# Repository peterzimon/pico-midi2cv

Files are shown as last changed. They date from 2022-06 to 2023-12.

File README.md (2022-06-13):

# MIDI to CV converter



## About
A simple MIDI to CV converter using MCP4288 DAC.

## Dependecies
Uses [`pico-lib`](https://github.com/peterzimon/pico-lib) submodule. Clone and pull 
with `--recurse-submodules`, or use `git submodule update --init` once cloned. 

Alternatively you can set `git config submodule.recurse true` or `git config --global submodule.recurse true`.

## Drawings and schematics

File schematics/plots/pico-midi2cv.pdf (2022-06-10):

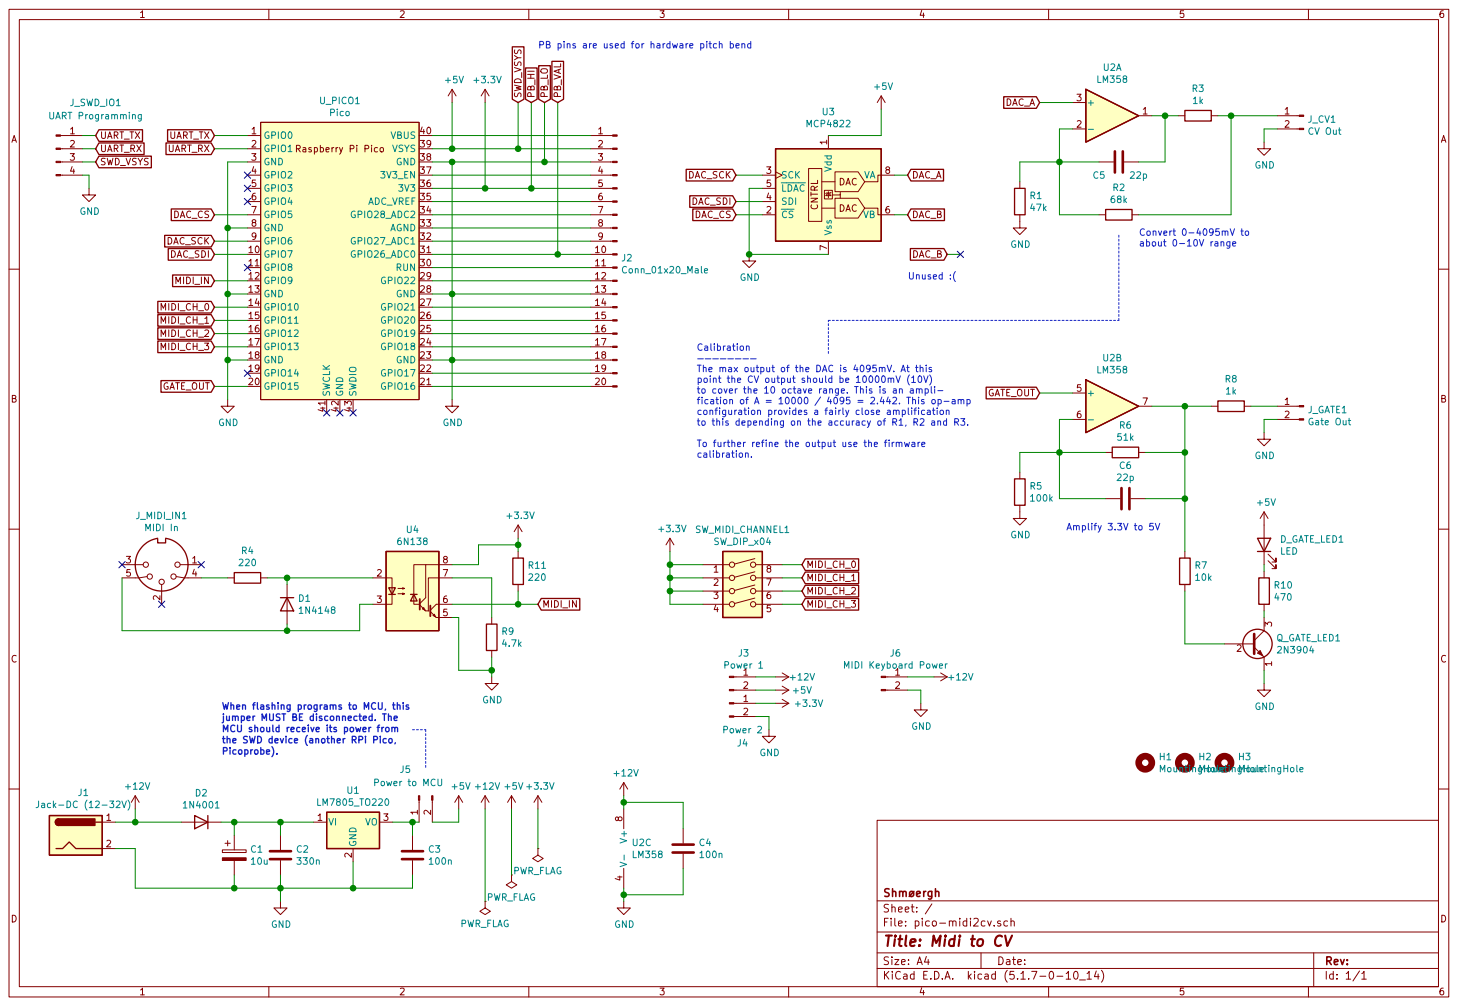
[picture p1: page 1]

Amplify 3.3V to 5V Calibration The max output of the DAC is 4095mV. At this

point the CV output should be 10000mV (10V)
to cover the 10 octave range. This is an ampli-
fication of A = 10000 / 4095 = 2.442. This op-amp
configuration provides a fairly close amplification
to this depending on the accuracy of R1, R2 and R3.

To further refine the output use the firmware

When flashing programs to MCU, this
jumper MUST BE disconnected. The
MCU should receive its power from
the SWD device (another RPi Pico,
Picoprobe).

File: pico-midi2cv.sch Sheet: / Shmøergh

Id: 1/1 Title: Midi to CV

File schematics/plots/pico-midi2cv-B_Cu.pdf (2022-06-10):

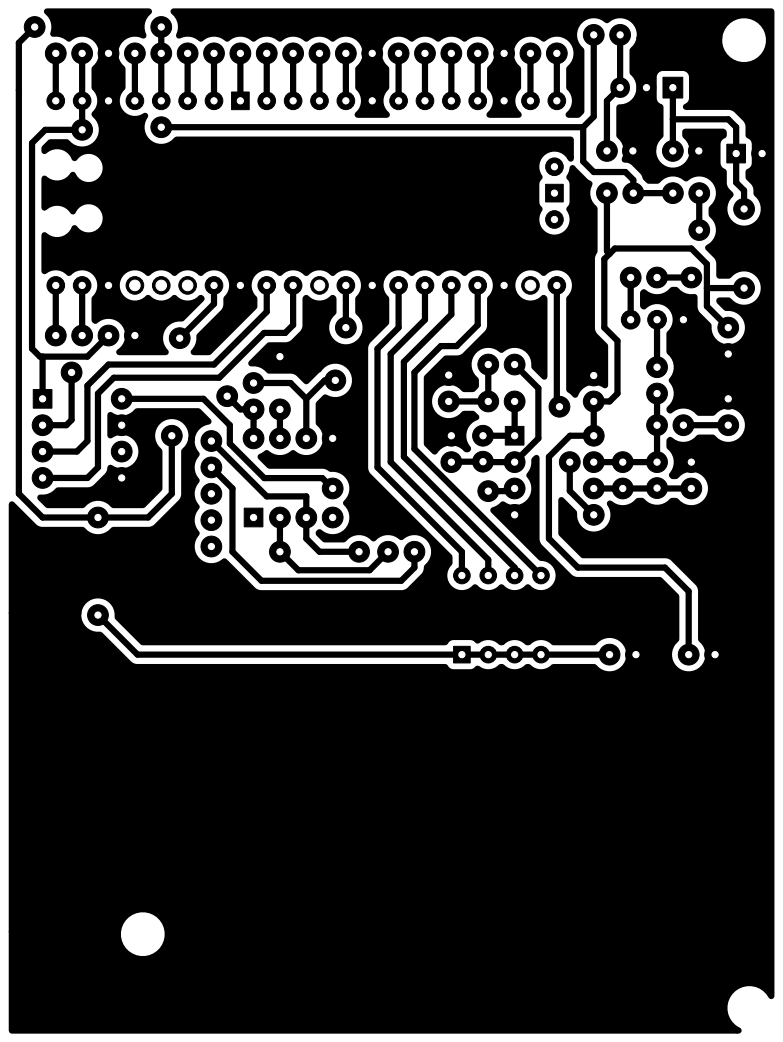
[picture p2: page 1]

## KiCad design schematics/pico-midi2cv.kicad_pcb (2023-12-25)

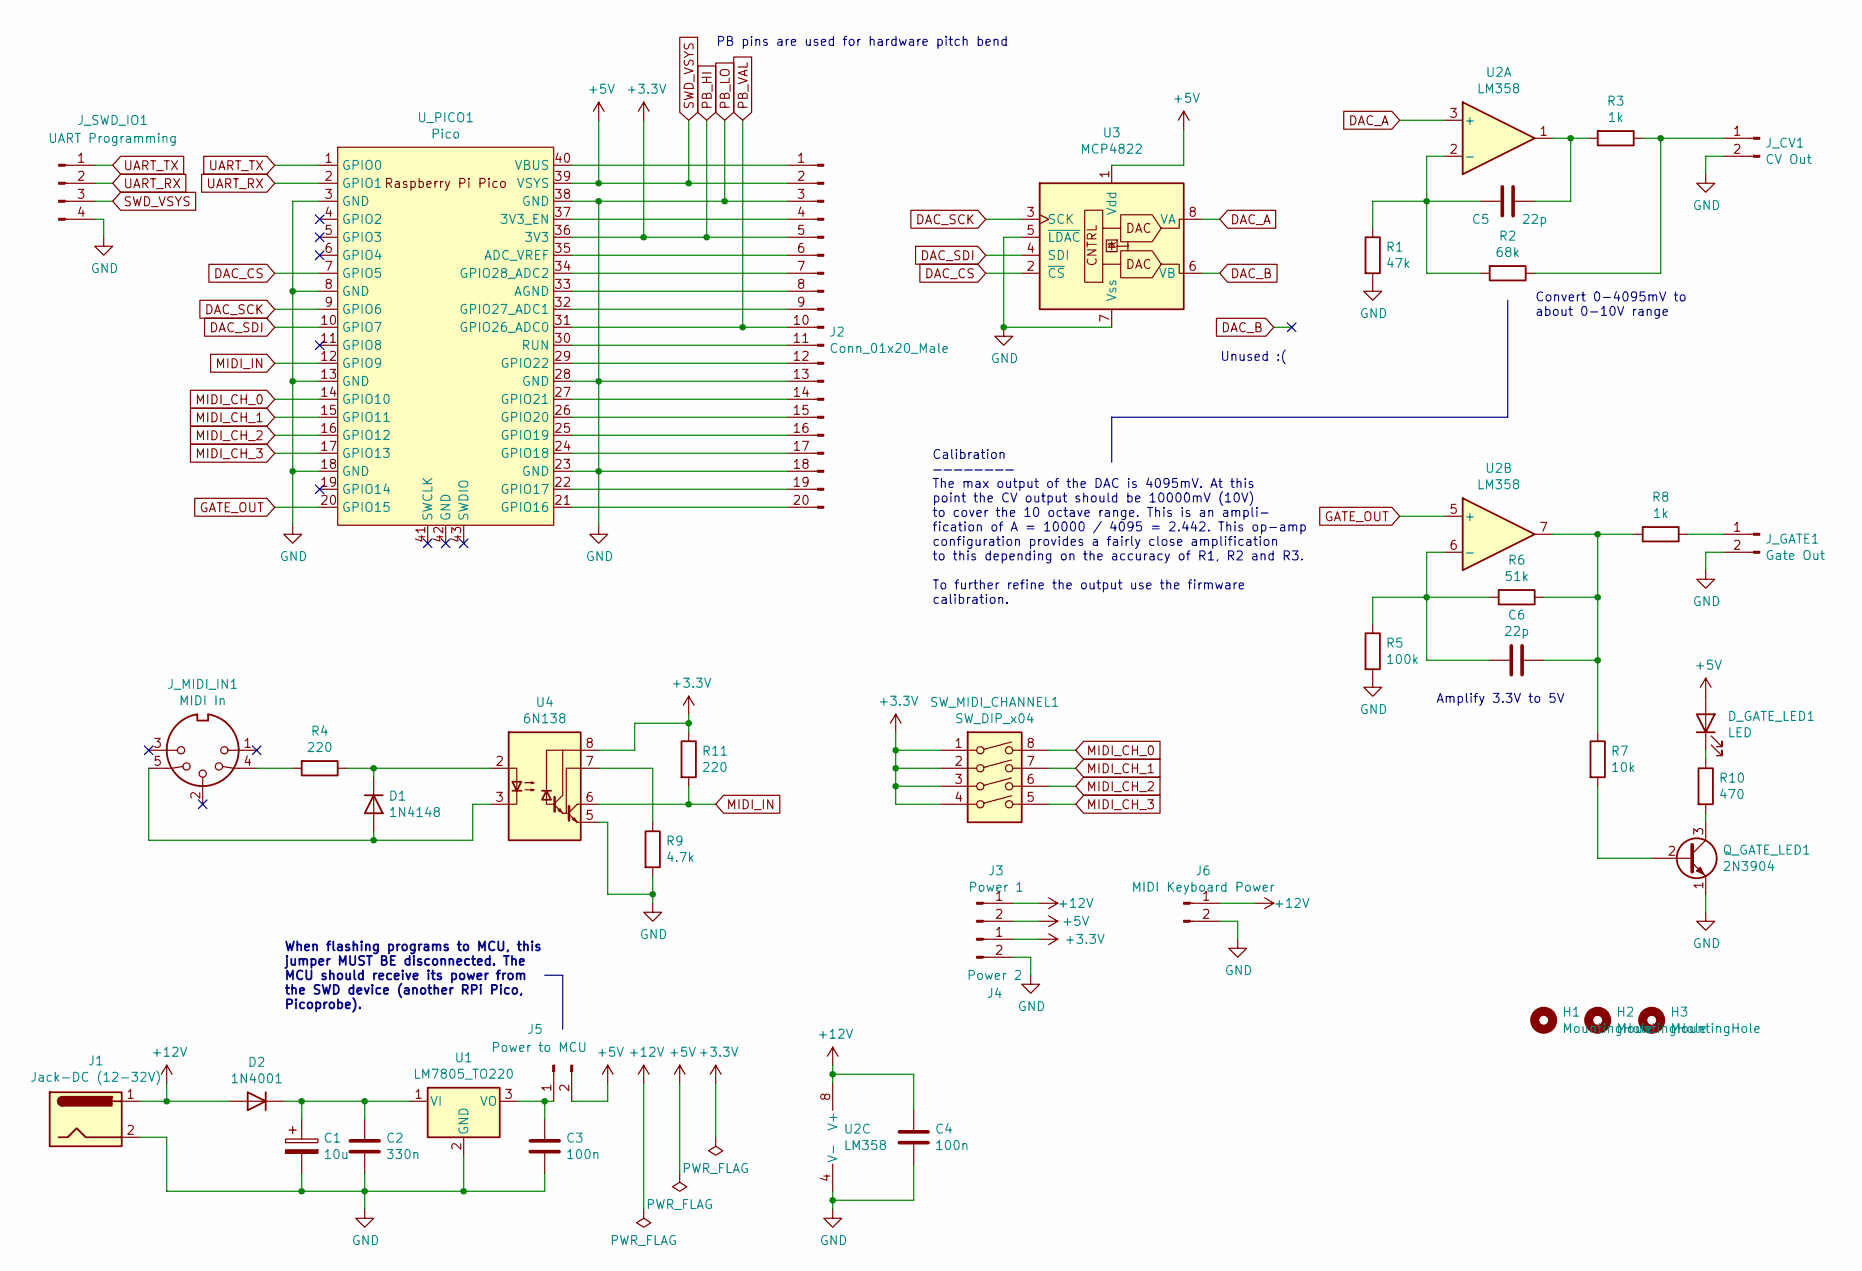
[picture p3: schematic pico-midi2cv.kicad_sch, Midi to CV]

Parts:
C1: 10u; CP_Radial_D5.0mm_P2.50mm
C2: 330n; C_Disc_D5.0mm_W2.5mm_P2.50mm
C3, C4: 100n; C_Disc_D5.0mm_W2.5mm_P2.50mm
C5, C6: 22p; C_Disc_D5.0mm_W2.5mm_P2.50mm
D1: 1N4148; D_Axial
D2: 1N4001; D_Axial
D_GATE_LED1: LED; NSL25_01x02_Vertical
H1, H2, H3: MountingHole; MountingHole_3mm
J1: Jack-DC (12-32V); NSL25_01x02_Vertical
J2: Conn_01x20_Male; PinOut_01x20
J3: Power 1; NSL25_01x02_Vertical
J4: Power 2; NSL25_01x02_Vertical
J5: Power to MCU; PinOut_01x02
J6: MIDI Keyboard Power; NSL25_01x02_Vertical
J_CV1: CV Out; NSL25_01x02_Vertical
J_GATE1: Gate Out; NSL25_01x02_Vertical
J_MIDI_IN1: MIDI In; PinOut_01x05
J_SWD_IO1: UART Programming; PinOut_01x04
Q_GATE_LED1: 2N3904; TO-92_Inline_Wide
R1: 47k; R_Axial_Vertical
R2: 68k; R_Axial_Vertical
R3, R8: 1k; R_Axial_Vertical
R4, R11: 220; R_Axial_Vertical
R5: 100k; R_Axial_Vertical
R6: 51k; R_Axial_Vertical
R7: 10k; R_Axial_Vertical
R9: 4.7k; R_Axial_Vertical
R10: 470; R_Axial_Vertical
SW_MIDI_CHANNEL1: SW_DIP_x04; SW_DIP_SPSTx04_Slide_6.7x11.72mm_W7.62mm_P2.54mm_LowProfile
U1: LM7805_TO220; TO-220-3_Vertical
U2: LM358; DIP-8_W7.62mm
U3: MCP4822; DIP-8_W7.62mm
U4: 6N138; DIP-8_W7.62mm
U_PICO1: Pico; RPi_Pico_SMD_TH

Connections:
+12V: C4.1, D2.2 (A), J1.1, J3.1, J6.1, U2.8 (V+)
DAC_A: U2.3 (+), U3.8 (VA)
DAC_B: U3.6 (VB)
DAC_CS: U3.2 (~CS), U_PICO1.7 (GPIO5)
DAC_SCK: U3.3 (SCK), U_PICO1.9 (GPIO6)
DAC_SDI: U3.4 (SDI), U_PICO1.10 (GPIO7)
GATE_OUT: U2.5 (+), U_PICO1.20 (GPIO15)
MIDI_CH_0: SW_MIDI_CHANNEL1.8, U_PICO1.14 (GPIO10)
MIDI_CH_1: SW_MIDI_CHANNEL1.7, U_PICO1.15 (GPIO11)
MIDI_CH_2: SW_MIDI_CHANNEL1.6, U_PICO1.16 (GPIO12)
MIDI_CH_3: SW_MIDI_CHANNEL1.5, U_PICO1.17 (GPIO13)
MIDI_IN: R11.2, U4.6 (VO2), U_PICO1.12 (GPIO9)
unnamed: C1.1, C2.1, D2.1 (K), U1.1 (VI)
unnamed: C3.1, J5.1, U1.3 (VO)
unnamed: C5.1, R3.2, U2.1
unnamed: C5.2, R1.1, R2.2, U2.2 (-)
unnamed: C6.1, R6.1, R7.1, R8.2, U2.7
unnamed: C6.2, R5.1, R6.2, U2.6 (-)
unnamed: D1.1 (K), R4.1, U4.2 (C1)
unnamed: D1.2 (A), J_MIDI_IN1.5, U4.3 (C2)
unnamed: D_GATE_LED1.1 (K), R10.1
unnamed: J2.1, U_PICO1.40 (VBUS)
unnamed: J2.4, U_PICO1.37 (3V3_EN)
unnamed: J2.6, U_PICO1.35 (ADC_VREF)
unnamed: J2.7, U_PICO1.34 (GPIO28_ADC2)
unnamed: J2.8, U_PICO1.33 (AGND)
unnamed: J2.9, U_PICO1.32 (GPIO27_ADC1)
unnamed: J2.11, U_PICO1.30 (RUN)
unnamed: J2.12, U_PICO1.29 (GPIO22)
unnamed: J2.14, U_PICO1.27 (GPIO21)
unnamed: J2.15, U_PICO1.26 (GPIO20)
unnamed: J2.16, U_PICO1.25 (GPIO19)
unnamed: J2.17, U_PICO1.24 (GPIO18)
unnamed: J2.19, U_PICO1.22 (GPIO17)
unnamed: J2.20, U_PICO1.21 (GPIO16)
unnamed: J_CV1.1, R2.1, R3.1
unnamed: J_GATE1.1, R8.1
unnamed: J_MIDI_IN1.4, R4.2
unnamed: Q_GATE_LED1.2 (B), R7.2
unnamed: Q_GATE_LED1.3 (C), R10.2
unnamed: R9.1, U4.7 (VO1)
PB_HI: J2.5, J4.1, R11.1, SW_MIDI_CHANNEL1.1, SW_MIDI_CHANNEL1.2, SW_MIDI_CHANNEL1.3, SW_MIDI_CHANNEL1.4, U4.8 (VCC), U_PICO1.36 (3V3)
PB_LO: C1.2, C2.2, C3.2, C4.2, J1.2, J2.3, J2.13, J2.18, J4.2, J6.2, J_CV1.2, J_GATE1.2, J_SWD_IO1.4, Q_GATE_LED1.1 (E), R1.2, R5.2, R9.2, U1.2 (GND), U2.4 (V-), U3.5 (~LDAC), U3.7 (Vss), U4.5 (GND), U_PICO1.3 (GND), U_PICO1.8 (GND), U_PICO1.13 (GND), U_PICO1.18 (GND), U_PICO1.23 (GND), U_PICO1.28 (GND), U_PICO1.38 (GND)
PB_VAL: J2.10, U_PICO1.31 (GPIO26_ADC0)
SWD_VSYS: D_GATE_LED1.2 (A), J2.2, J3.2, J5.2, J_SWD_IO1.3, U3.1 (Vdd), U_PICO1.39 (VSYS)
UART_RX: J_SWD_IO1.2, U_PICO1.2 (GPIO1)
UART_TX: J_SWD_IO1.1, U_PICO1.1 (GPIO0)

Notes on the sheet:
Amplify 3.3V to 5V
PB pins are used for hardware pitch bend
Convert 0-4095mV to about 0-10V range
Unused :(
When flashing programs to MCU, this jumper MUST BE disconnected. The MCU should receive its power from the SWD device (another RPi Pico, Picoprobe).
Calibration ———————— The max output of the DAC is 4095mV. At this point the CV output should be 10000mV (10V) to cover the 10 octave range. This is an ampli- fication of A = 10000 / 4095 = 2.442. This op-amp configuration provides a fairly close amplification to this depending on the accuracy of R1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

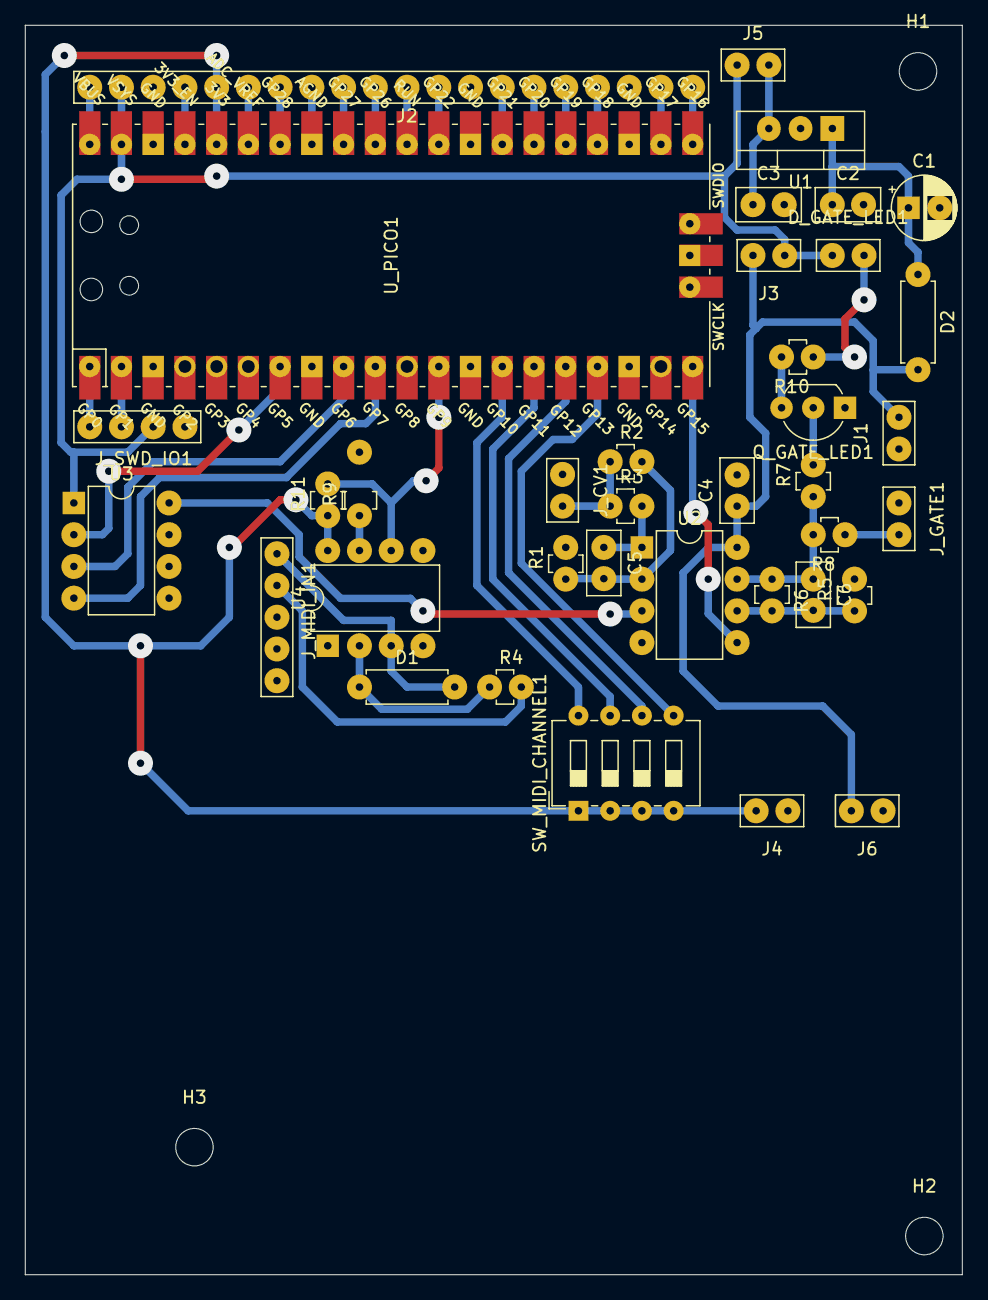
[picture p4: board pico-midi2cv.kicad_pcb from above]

Board: 2 copper layers, 75.0 x 100.0 mm, 40 parts (0 on the bottom side), 46 nets.

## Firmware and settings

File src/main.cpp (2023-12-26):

/**
 * @author Peter Zimon (peterzimon.com)
 * @copyright Copyright (c) 2022
 *
 * Base logic
 * ----------
 * There are two main working modes: if the sequencer is playing (receives clock
 * signal or uses internal clock) then the incoming MIDI data is used for
 * setting the sequencer notes. If the sequencer is not playing then the MIDI
 * input is converted to CV and gate output.
 *
 * Building blocks (classes)
 * -------------------------
 * MidiHandler
 * - Sets up uart for incoming MIDI
 * - Parses MIDI using midi_parser library
 * - Saves notes in a note stack for last-note-priority output
 *
 * MidiToCV
 * - Looks up the MIDI channel setting. Note that MIDI channel setting is only
 *   scanned at boot. If you change the MIDI channel then you have to reboot
 *   the system.
 * - Sets dac CV voltage based on the midi_handler note stack
 * - Sets gate gpio
 * - Saves settings for MIDI to CV conversion (if there's any)
 *
 * UI
 * - Handles gpio for UI
 *
 * Connections
 * -----------
 * midi_to_cv.attach(midi_handler)
 * midi_to_cv.attach(dac)
 * midi_to_cv.attach(ui)
 *
 * Flashing
 * --------
 * DISCONNECT FROM POWER BEFORE FLASHING!!!!
 */

/*
 * C++ headers
 */
#include <iostream>
#include <string>
#include <vector>
#include <cstdlib>
#include <cstdint>
#include <cstring>

/*
 * Pico headers
 */
#include "pico/stdlib.h"
#include "pico/binary_info.h"
#include "hardware/gpio.h"
#include "hardware/spi.h"
#include "hardware/adc.h"
#include "hardware/uart.h"

/*
 * Custom libraries
 */
#include <mcp48x2.h>

/*
 * Project headers
 */
#include "settings.h"
#include "midi_handler.h"
#include "ui.h"
#include "midi_to_cv.h"

Settings settings;
MCP48X2 dac;
MidiHandler midi_handler;
UI ui;
MidiToCV midi_to_cv;

int main() {
    stdio_init_all();

    sleep_ms(2000);
    ui.init();
    dac.init(DAC_SPI_PORT, GP_DAC_CS, GP_DAC_SCK, GP_DAC_MOSI);
    midi_handler.init();
    midi_to_cv.init();

    midi_to_cv.attach(&midi_handler);
    midi_to_cv.attach(&dac);
    midi_to_cv.attach(&ui);

    while (1) {
        ui.update();
        midi_to_cv.process();
    }

    return 0;
}

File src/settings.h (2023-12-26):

#ifndef _SETTINGS_H
#define _SETTINGS_H

#include <inttypes.h>
#include <pico/stdio.h>
#include "hardware/spi.h"
#include "hardware/uart.h"

/**
 * Contains constants and enums.
 *
 * Note that all "GP_..." constant refers to the GP port of the Raspberry Pi
 * Pico, not the actual physical pin. Example:
 *
 *      GP_DAC_CS 5 means GP5 = physical pin 7
 *
 * Calibration
 * -----------
 * Since all electrical components have slightly different characteristics, the
 * final output voltage may differ from voice to voice (CV+Gate pairs). Follow the
 * process below to calibrate each voice's CV output:
 *
 * 0. According to the V/octave standard, all C's should output a rounded voltage
 *    value. C1 (ie. the 2nd octave C, MIDI note 12) should generate 1V, C2 should
 *    2V and so on. Midipoly can output 10 octaves so the first 10 octave on your
 *    MIDI keyboard should output 1, 2 ... 10 volts respectively.
 * 1. Use a precision multimeter and measure the CV output voltage. Note that
 *    when you don't press a key the output voltage is not precisely 0V due to
 *    imperfection and leakage current. This is something you can't calibrate.
 * 2. Press C1 on your MIDI keyboard. You should read around 1V on the multimeter.
 *    If it's higher than 1V then you'll need to set an adjustment value for the
 *    1st voice's 1st octave C. In order to do this, open cvgate.cpp and set the
 *    _cal[0][1] to some negative value. Setting it to -1 will case a about 2mV
 *    drop in the output. So _cal[0][1] sets the first voice ("0" -> first voice)
 *    first octave ("1" that's supposed to be 1V).
 * 3. Upload the firmware and check the output voltage again. If it's 1-2mV close
 *    then you can go to the next octave. Do this until all the octaves (0-10)
 *    show the appropriate voltage on the given voice.
 *
 * calibration[Cx] = RELATIVE ADJUSTMENT VALUE
 *              ^               ^
 *              ^               Use negative values to decrease the CV output
 *              C note on given octave. Should output xV (C1 -> 1V, C2 -> 2V etc.) [0-10]
 */

// DAC
#define DAC_SPI_PORT        spi0
#define GP_DAC_CS           5
#define GP_DAC_SCK          6
#define GP_DAC_MOSI         7

// MIDI
#define LOWEST_MIDI_NOTE    0x00
#define OCTAVES             10
#define MAX_PITCH_BEND      0x3fff
#define PITCH_BEND_CENTER   0x2000
#define MAX_PB_SEMINOTES    2

#define GP_CHANNEL_DIP_0    13
#define GP_CHANNEL_DIP_1    12
#define GP_CHANNEL_DIP_2    11
#define GP_CHANNEL_DIP_3    10

#define MIDI_OCTAVE_SHIFT   -2

#define MIDI_UART_INSTANCE  uart1
#define GP_MIDI_RX          9
#define MIDI_BAUDRATE       31250

// CV
#define MAX_NOTE_VOLTAGE    4095
#define GP_GATE             15

// ADC
#define ADC_GP_PITCHBEND    26 // GPIO26
#define HW_PB_MAX_DIFF      1900 // Decimal value of max difference of hardware
                                 // pitch value compared to reference. The Pico
                                 // ADC is a piece of shit, will never be 0
                                 // or 4095 as it supposed to be. This value
                                 // determines the max/min values that the
                                 // pitchbend is measured until. So e.g. if
                                 // the pitchbend reference is 2032 and the max
                                 // diff value is 1900 then the maximum measured
                                 // value can only be 3932 (not 4095). This will
                                 // represent 0x3fff pitchbend value in MIDI
                                 // terms.

struct Settings
{
    int calibration[11] = {

                // Note  | Should measure
                //----------------------------
        0,      // C0    | 0V, leave this zero
        5,      // C1    | 1V
        4,      // C2    | 2V
        6,      // C3    | 3V
        3,      // C4    | 4V
        0,      // C5    | 5V
        0,      // C6    | 6V
        0,      // C7    | 7V
        0,      // C8    | 8V
        0,      // C9    | 9V
        0,      // C10   | 10V
    };

    uint8_t midi_channel = 0;
};

extern Settings settings;

#endif

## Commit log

2022-01-30 Added pico-lib submodule
2022-01-30 Updated CMakeLists to include pico-lib
2022-02-02 Updated midi to cv logic + created schematics
    [pico-midi2cv.kicad_pcb, pico-midi2cv.sch]
2022-02-02 Fixed pitch bend + optimize performance
    [midi.cpp, midi_to_cv.cpp]
2022-06-03 Updated schematics
    [pico-midi2cv.sch]
2022-06-03 Uploaded schematics pdf's
2022-06-06 Added MIDI channel DIP switch
    [pico-midi2cv.kicad_pcb, pico-midi2cv.sch]
2022-06-07 Added top 20 pin outs to PCB and further updates
    [pico-midi2cv.kicad_pcb, pico-midi2cv.sch]
2023-12-25 Updated to KiCad7 format
    [pico-midi2cv.kicad_pcb, pico-midi2cv.kicad_sch, pico-midi2cv.sch]
